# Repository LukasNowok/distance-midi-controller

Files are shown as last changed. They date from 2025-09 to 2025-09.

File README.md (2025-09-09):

# distance-midi-controller
**A high-precision, low-latency MIDI controller that turns hand and body gestures into expressive musical control, using a VL53L0X ToF distance sensor in a 3D-printed case mountable on any microphone stand: open-source and ready to be modified and hacked.**

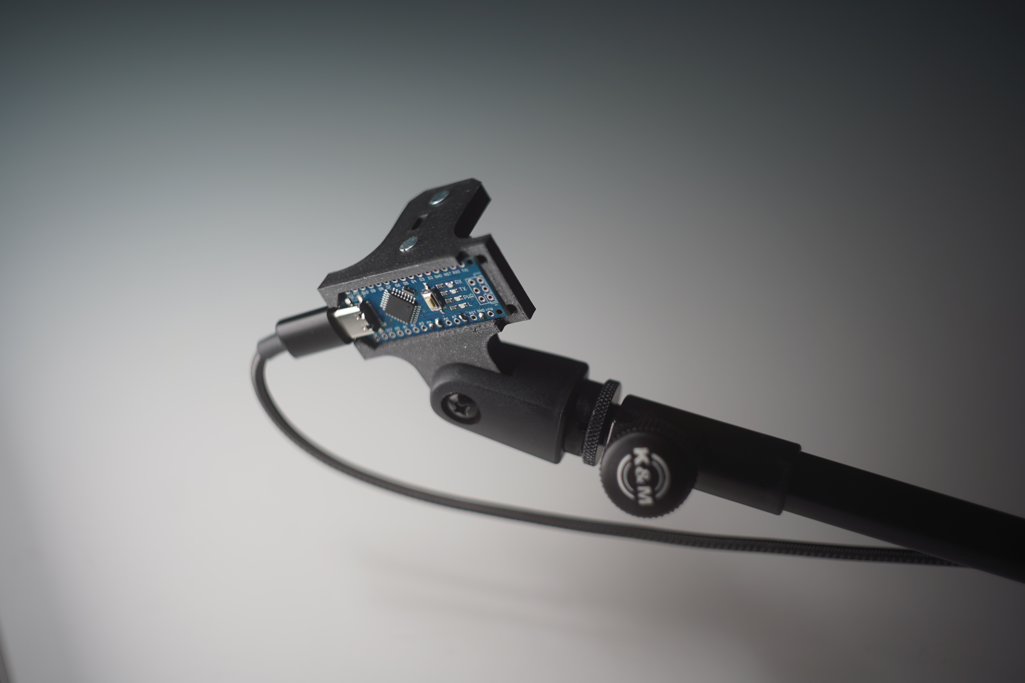
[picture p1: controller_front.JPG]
front view of the controller mounted onto a mic stand


rear view of the controller showing the wiring

## Features
- **Hands-Free Control:** Modulate MIDI parameters gesturally
- **High Precision & Low Latency:** Utilizes the VL53L0X Time of Flight (ToF) sensor with optimised readout for gestural control and fine-tuned balance between latency and acuracy.
- **Microphone Stand Mountable:** The 3D printed case is designed to be mounted on any standard microphone stand for easy and flexible placement of the controller
- **Low Cost & Easy to Build & Modify:** Houses a standard off-the-shelf VL53L0X sensor bord and any microcontroller with 43x17mm footprint

## Hardware
- 1 Arduino Nano or compatible microcontroller
- 1 VL53L0X dev board. We've been using [this one](https://www.az-delivery.de/en/products/vl53l0x-time-of-flight-tof-laser-abstandssensor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)
- [K&M 85055 microphone clamp](https://www.k-m.de/en/products/microphone-stands/accessories/microphone-clips/85055-microphone-clip-black-3-8-and-5-8) The lower section of this is used to hold the 3D printed housing and provides a thread for mic stands. Just unscrew the 'clamp' part and keep the threaded bottom part.
- 4 x 3cm of thin gague wire to connect the ToF sensor to the microcontroller. 2mm diameter including the insulation fits fine.
- 2 M3*10mm countersunk screws & 2 x M3 nuts. These are used to mount the sensor to the housing.

## Software & Setup
1. **Install Arduino IDE:** If you don't already have it, download and install the [Arduino IDE](https://www.arduino.cc/en/software/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).
2. **Install Libraries:**
  - Open the Arduino IDE and go to Sketch > Include Library > Manage Libraries....
  - Search for and install the VL53L0X library by Pololu (this allows for a few more options to fine-tune the sensor readout)
  - Search for and install the MIDIUSB library by Gary Grewal (for future iterations of the controller)
3. **Upload the Code:**
  - Clone or download this repository.
  - Open the tof_controller.ino file in the Arduino IDE.
  - Select your board and port from the Tools menu.
  - Modify CCNUMBER and CCCHANNEL at the top of the sketch to fit your needs.
  - Click the "Upload" button.

## 3D Printed Enclosure
The STL file for the enclosure is included in this repo.
- **Recommended Material:** PETG or PLA
- **Infill:** 50% or more. The rounded part of the print is going to be clamped into the mic-holder and has to withstand a bit of pressure.
- **Layer Height:** 0.12mm. This provides a precise cutout for the microcontroller slot, allowing the Arduino to be press-fit and held in place by friction.
- **Enable Supports** for the overhang in the microcrontroller-slot, the pin-cutout and screwholes.

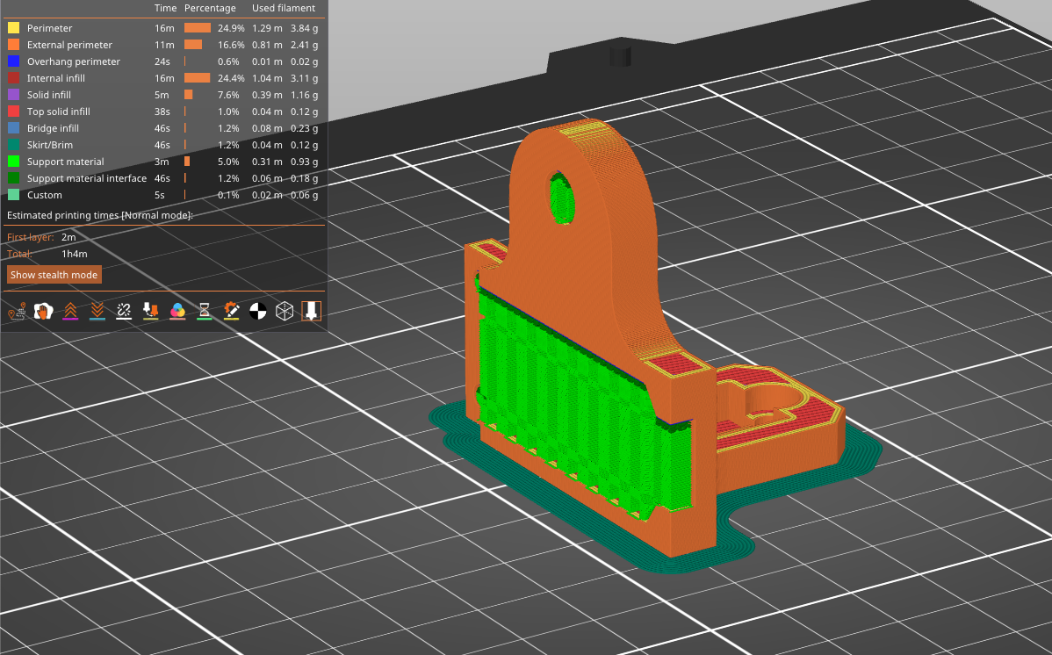
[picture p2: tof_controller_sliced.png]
view of the enclosure sliced in the prusa slicer


## Assembly
1. **Prepare VL53L0X board:** Solder 4 short wires onto pins VCC, GND, SCL & SDA
2. **Mount VL53L0X board onto enclosure** using the M3 screws and nuts
3. **Press Arduino into enclosure.** The tolerances in the print should hold it in place but you might need to experiment with layerheights if it doesn't fit.
4. **Solder VL53L0X to Arduino:** Connect the wires you previously soldered to the sensor board to the Arduino:
  - 5V -> VCC
  - GND -> GND
  - A5 -> SCL
  - A4 -> SDA
5. **Mount Enclosure on Microphone Holder.** The printed enclosure fits the [K&M 85055 microphone clamp](https://www.k-m.de/en/products/microphone-stands/accessories/microphone-clips/85055-microphone-clip-black-3-8-and-5-8) perfectly, but should be easy enough to adjust to different holders.

## Usage
1. Mount the controller on a microphone stand and position it as desired.
2. Connect it to your computer via a USB cable.
3. Open serial2midi.maxpat. The controller will be recognized as a serial device. From there it can be re-routed to a MIDI output.
4. In your DAW or music software, enter MIDI mapping mode.
5. Select the parameter you wish to control (e.g., a synth filter cutoff).
6. Move your hand in front of the sensor. The software should detect the incoming MIDI CC message and assign it to your selected parameter.

## Roadmap
- Replace Arduino Nano with Arduino Pro Micro so the board can act directly as a class-compliant MIDI device
  - at the moment, the microcontroller is generating serial data which has to be converted to MIDI by the host machine (see serial2midi.maxpat). Thats an extra step that should be eliminated by using any controller with the ATmega32U4 chip.
- Redesign 3D printed housing to a cylindrical design
   - protect Arduino inside an enclosure
   - place USB-C port on the bottom for better cable-routing
- Configurable MIDI mapping via serial or web UI
- Extend and test distance range to allow for wider range of movement

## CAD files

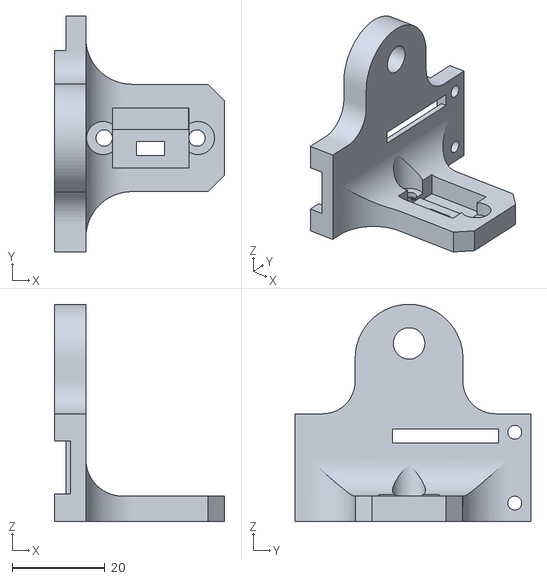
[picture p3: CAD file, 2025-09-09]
tof_controller.stl
36.8 x 51.0 x 46.9

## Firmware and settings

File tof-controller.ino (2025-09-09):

/* This example shows how to use continuous mode to take
range measurements with the VL53L0X. It is based on
vl53l0x_ContinuousRanging_Example.c from the VL53L0X API.

The range readings are in units of mm. */

#include <Wire.h>
#include <VL53L0X.h>
#include <MIDI.h>

VL53L0X sensor;

#define HIGH_SPEED
#define CCNUMBER 1
#define CCCHANEL 1
MIDI_CREATE_DEFAULT_INSTANCE();

int cc = 0;
unsigned long prevTime = 0;
int noteFlag = 0;

void setup() {
  delay(500);
  // Serial.begin(9600);
  Wire.setClock(10000);
  Wire.begin();
  Wire.setWireTimeout(3000 /* us */, true /* reset_on_timeout */);
  MIDI.begin(4);  // Launch MIDI and listen to channel 4

  sensor.setTimeout(500);
  if (!sensor.init()) {
    //Serial.println("Failed to detect and initialize sensor!");
    while (1) {}
  }

  sensor.setMeasurementTimingBudget(18000);

  // Setting a lower limit increases 
  // the potential range of the sensor 
  // but also increases the likelihood of getting 
  // an inaccurate reading because of reflections 
  // from objects other than the intended target. 
  // This limit is initialized to 0.25 MCPS by default. 
  //  try adjusting this to fine-tune the range/responsiveness
  sensor.setSignalRateLimit(0.5);
  // Serial.print(sensor.getSignalRateLimit());

  // Start continuous back-to-back mode (take readings as
  // fast as possible).  To use continuous timed mode
  // instead, provide a desired inter-measurement period in
  // ms (e.g. sensor.startContinuous(100)).
  sensor.startContinuous();
}

void loop() {
  uint16_t range = 0;
  if ((sensor.readReg(sensor.RESULT_INTERRUPT_STATUS) & 0x07) != 0) {
    range = sensor.readReg16Bit(sensor.RESULT_RANGE_STATUS + 10);
    sensor.writeReg(sensor.SYSTEM_INTERRUPT_CLEAR, 0x01);

    // Serial.println(millis() - prevTime); // elapsed time for measurement
    // Serial.println(range);

    if ((millis() - prevTime) < 16 && noteFlag == 1) {
      MIDI.sendNoteOff(1, 0, 1);
      noteFlag = 0;
    };

    if (range > 2000) {
      MIDI.sendControlChange(CCNUMBER, 0, CCCHANEL);
    } else {
      cc = constrain(map(range, 0, 700, 0, 127), 0, 127);
      MIDI.sendControlChange(CCNUMBER, cc, CCCHANEL);
    };
    prevTime = millis();
  };

  // send separate cc & note on/off
  // note will be ~13ms faster, because measurement takes ~31ms
  // but note triggers after 18ms... yey 13ms !
  if ((millis() - prevTime) > 20 && noteFlag == 0) {
    // MIDI.sendNoteOn(1, 127, 1);
    noteFlag = 1;
  };

///////////////////////////////////////////////
  /////////// stock library version ///////////
  // int distanceReading = sensor.readRangeContinuousMillimeters();
  // cc = constrain(map(distanceReading, 0, 700, 0, 127), 0, 127);
  // if (distanceReading > 6000){
  //   MIDI.sendControlChange(CCNUMBER, 0, CCCHANEL);
  // }
  // else
  // {
  //   MIDI.sendControlChange(CCNUMBER, cc, CCCHANEL);
  // }
}

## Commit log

2025-09-09 Add Arduino sketch
2025-09-09 Add Enclosure STL
    [tof_controller.stl]
